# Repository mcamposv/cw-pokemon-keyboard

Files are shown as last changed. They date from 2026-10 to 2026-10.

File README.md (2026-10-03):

# CWPokeKey — Adaptador de teclado USB para CW Pokemon

> [English version](README.en.md)

Firmware para ESP32-S3 que convierte la entrada de un teclado USB estándar al protocolo PS/2, permitiendo usarlo con el jack TRS 3.5mm del [CW Pokemon](https://github.com/admvip/CW-Pokemon-Infomation).

## Objetivo

El [CW Pokemon](https://github.com/admvip/CW-Pokemon-Infomation) es un dispositivo hardware para radioaficionados que decodifica y genera código Morse (CW). Solo acepta teclados PS/2 a través de su jack TRS 3.5mm. Este adaptador soluciona esa limitación usando un ESP32-S3 como host USB HID + transmisor PS/2 por bit-bang.

```
Teclado USB  →  ESP32-S3 (USB OTG Host)  →  PS/2 bit-bang  →  Jack TRS 3.5mm  →  CW Pokemon
```

**Proyecto CW Pokemon (hardware original):** [github.com/admvip/CW-Pokemon-Infomation](https://github.com/admvip/CW-Pokemon-Infomation)

## Lista de materiales

| Cantidad | Componente | Notas |
|---|---|---|
| 1 | ESP32-S3-DevKitC-1 N16R8 | 16 MB flash, 8 MB PSRAM |
| 1 | Jack TRS 3.5mm hembra estéreo (para soldar) | **Imprescindible estéreo** — ver aviso abajo |
| 1 | Cable TRS 3.5mm estéreo (macho-macho) | Para conectar el adaptador al CW Pokemon |
| 1 | Cable USB-C a USB-A OTG (macho-hembra) | Para conectar el teclado al puerto OTG del ESP32 |
| 1 | Cable USB-C | Alimentación del ESP32 (puerto derecho / UART) |
| 1 | Fuente o cargador USB 5V | Para alimentar el ESP32 |
| — | Estaño + soldador | Soldaduras en la placa |
| — | Pistola de hot glue | Sujetar y proteger las soldaduras |

> **Atención:** El jack TRS debe ser **estéreo** (3 contactos: TIP, RING, SLEEVE). Un conector mono (TS, 2 contactos) cortocircuitaría DATA con GND y podría dañar el CW Pokemon.

## Conexión del jack TRS (PS/2)

| Contacto TRS | Señal PS/2 | GPIO ESP32-S3 |
|---|---|---|
| TIP | DATA | GPIO5 |
| RING | CLK | GPIO6 |
| SLEEVE | GND | GND |

**Activar modo teclado en el CW Pokemon:** Menú → tipo de electrónico → **KeyB**

## Modificación hardware — activar USB Host

El DevKitC-1 tiene dos puentes de soldadura (*solder bridges*) en la PCB que hay que cerrar para que el puerto OTG izquierdo funcione como host y suministre alimentación al teclado. De fábrica vienen abiertos. Solo hace falta aplicar una pequeña gota de estaño en cada uno.

### Puente USB-OTG (cara trasera de la placa)

Está en la cara trasera, junto al conector USB-C izquierdo, marcado como **USB-OTG**. Cerrarlo habilita la salida de VBUS (5V) para alimentar el teclado.

| Abierto — estado de fábrica | Cerrado — aplicar estaño |
|:---:|:---:|
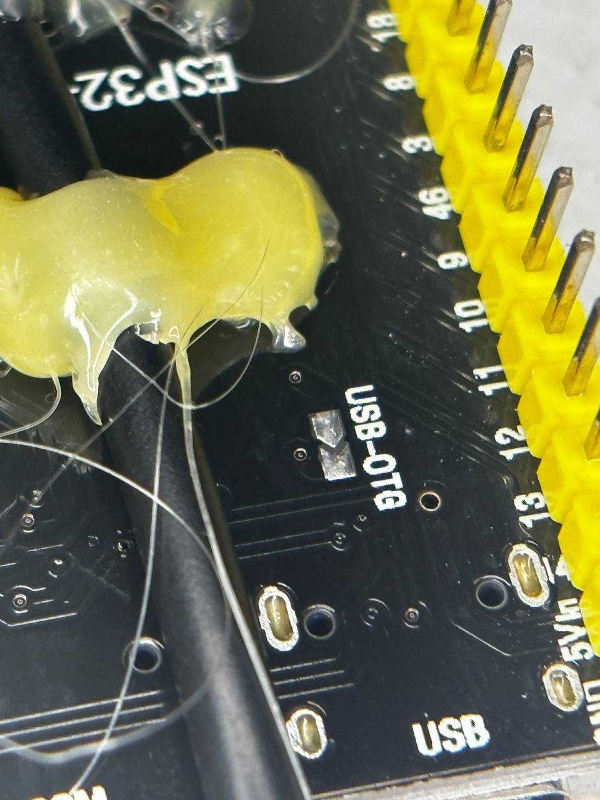
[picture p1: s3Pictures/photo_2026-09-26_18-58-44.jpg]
USB-OTG abierto
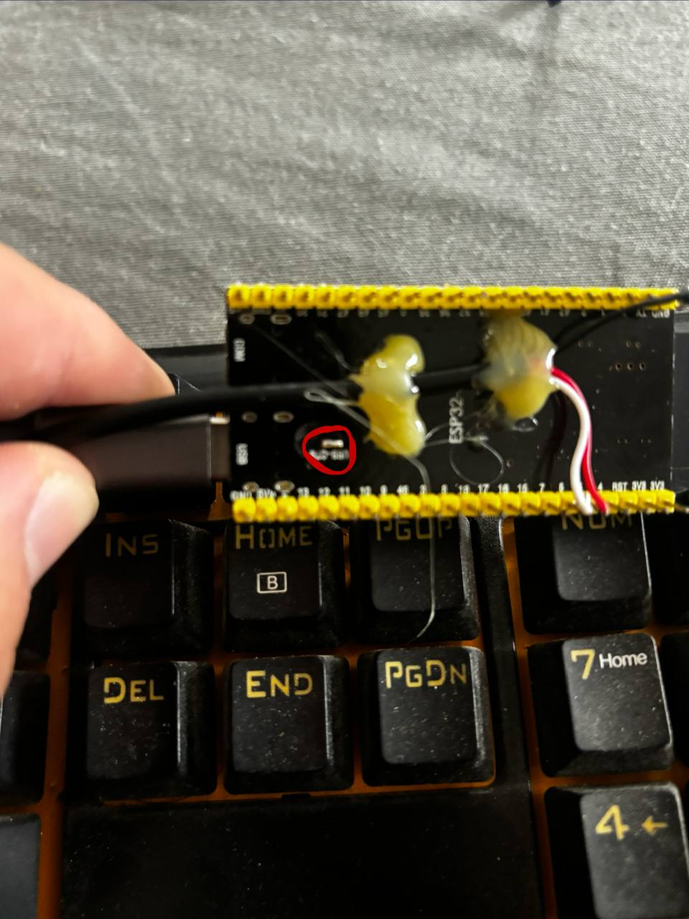
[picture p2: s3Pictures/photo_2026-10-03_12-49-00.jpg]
USB-OTG cerrado
|  |  |

### Puente IN-OUT (cara delantera de la placa)

Está en la cara delantera, también cerca del conector OTG, marcado como **IN-OUT**. Cerrarlo configura la dirección de corriente en modo host (salida). Los dos círculos rojos de la foto señalan ambos puentes ya cerrados.

| Abierto — estado de fábrica | Cerrado — aplicar estaño |
|:---:|:---:|
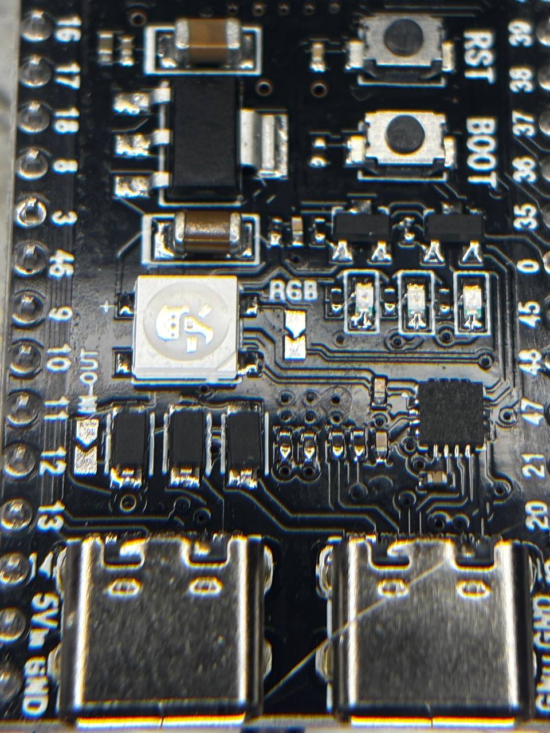
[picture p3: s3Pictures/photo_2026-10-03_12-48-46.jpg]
IN-OUT abierto
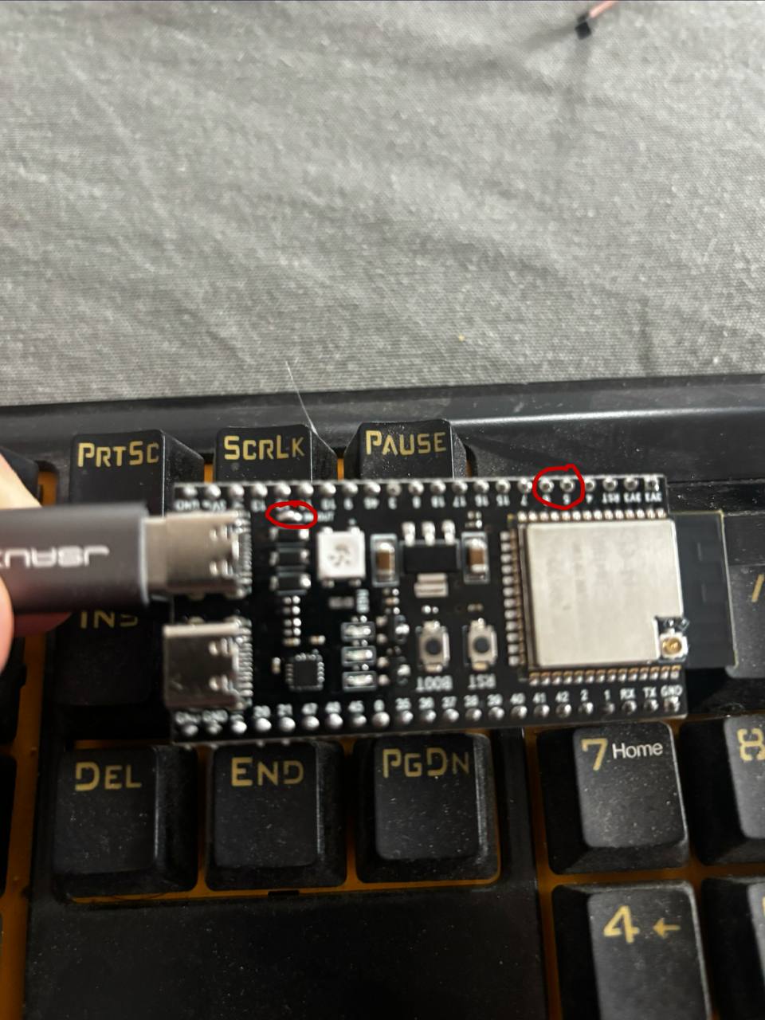
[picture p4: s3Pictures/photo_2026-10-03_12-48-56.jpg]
IN-OUT cerrado
|  |  |

### Vista general tras la modificación

| Cara delantera | Cara trasera |
|:---:|:---:|
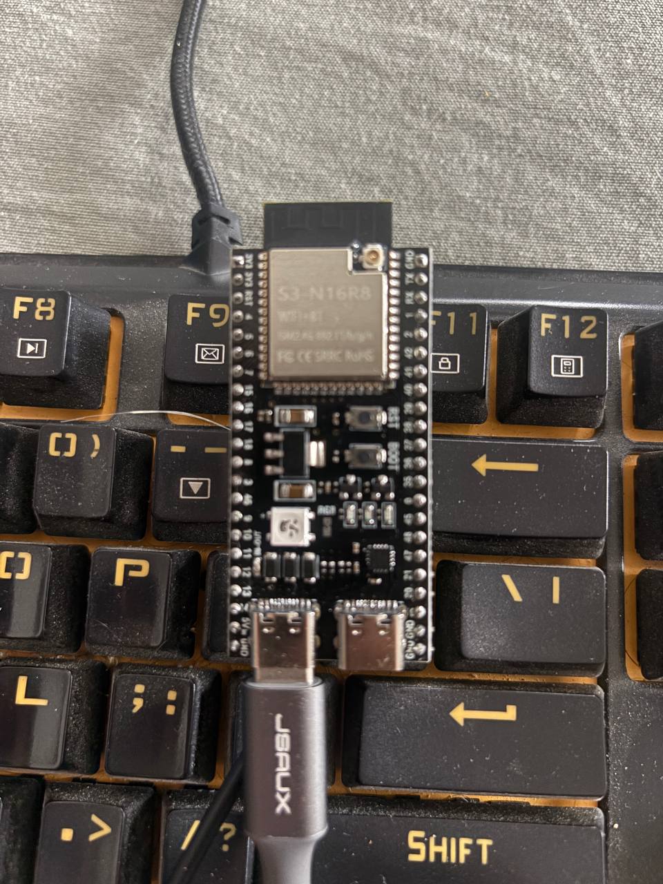
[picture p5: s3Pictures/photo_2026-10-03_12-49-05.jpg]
Vista frontal
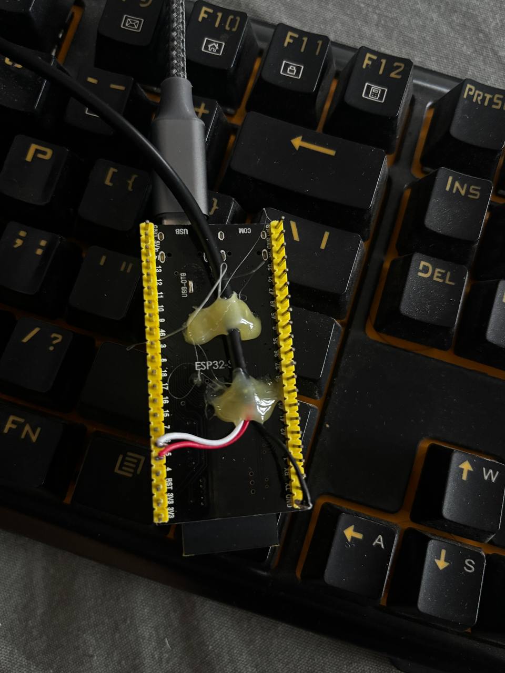
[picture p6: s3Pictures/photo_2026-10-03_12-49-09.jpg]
Vista trasera
|  |  |

## Notas eléctricas importantes

- El CW Pokemon usa lógica **3.3V** — no es necesario convertidor de nivel.
- El pin **CLK (RING)** tiene pull-up interno a **3.2V** en el CW Pokemon.
- El pin **DATA (TIP)** tiene un pull-down interno de **~8 kΩ a GND** en el CW Pokemon.
- **CRÍTICO — modo push-pull en DATA:** Con el pull-up interno de 45 kΩ del ESP32 en modo open-drain, la línea DATA solo alcanza ~0.5 V porque el pull-down de 8 kΩ del CW Pokemon gana. El CW Pokemon lee DATA como LOW constante y todo llega corrupto. Configurando el GPIO en **push-pull** (salida activa), el ESP32 conduce activamente 3.3 V y supera el pull-down. Implementado en `firmware-s3/src/ps2.cpp`.

## Indicador LED (WS2812 RGB, GPIO48)

| Estado | Comportamiento LED |
|---|---|
| Teclado USB conectado | Apagado |
| Esperando teclado | Azul, parpadeo rápido (~120 ms) |

## Compilar y flashear

Requiere [PlatformIO](https://platformio.org/) (extensión VS Code o CLI).

```bash
cd firmware-s3
pio run              # compilar
pio run -t upload    # flashear (puerto /dev/ttyACM0)
pio device monitor   # monitor serie (115200 baud)
```

### Selección de layout de teclado

Editar `firmware-s3/platformio.ini`:

```ini
build_flags =
    -DLAYOUT_ES   ; QWERTY español (por defecto)
;   -DLAYOUT_US   ; QWERTY inglés americano
```

## Caja imprimible en 3D

En la carpeta `box/` hay una caja parametrizada en OpenSCAD para alojar el adaptador. Los STL están listos para slicear directamente.

## Estructura del proyecto

```
firmware-s3/              — Firmware (USB HID Host + PS/2 bit-bang)
├── platformio.ini
└── src/
    ├── config.h          — Asignación de pines y constantes
    ├── ps2.cpp/hpp       — Driver PS/2 bit-bang (modo push-pull)
    ├── usb_kbd.cpp/hpp   — USB HID Host (ESP-IDF usb_host)
    ├── keymap.c/h        — Tabla HID keycode → PS/2 Set 2
    └── main.cpp
box/                      — Caja imprimible en 3D
├── cwpokekey_box.scad    — Fuente OpenSCAD (paramétrica)
├── cwpokekey_body.stl    — Cuerpo (imprimir sin soportes, suelo abajo)
└── cwpokekey_lid.stl     — Tapa  (imprimir sin soportes, cara exterior abajo)
s3Pictures/               — Fotos del hardware y soldaduras
debug/                    — Capturas de pantalla de depuración
```

## Licencia

GNU General Public License v3.0

Copyright (C) 2026 mcamposv

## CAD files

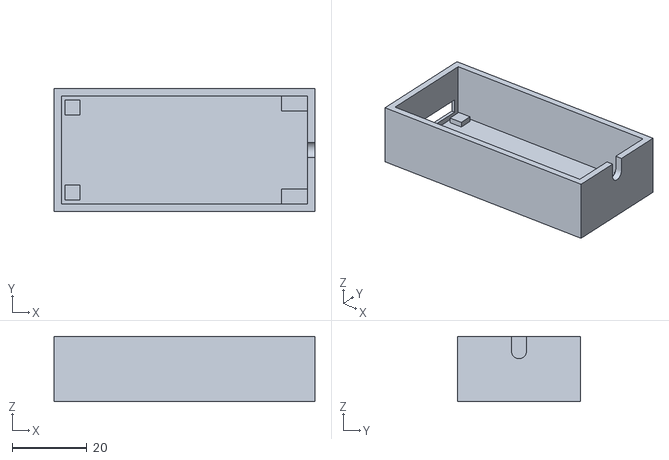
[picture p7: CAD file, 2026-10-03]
box/cwpokekey_body.stl
69.8 x 32.8 x 17.5

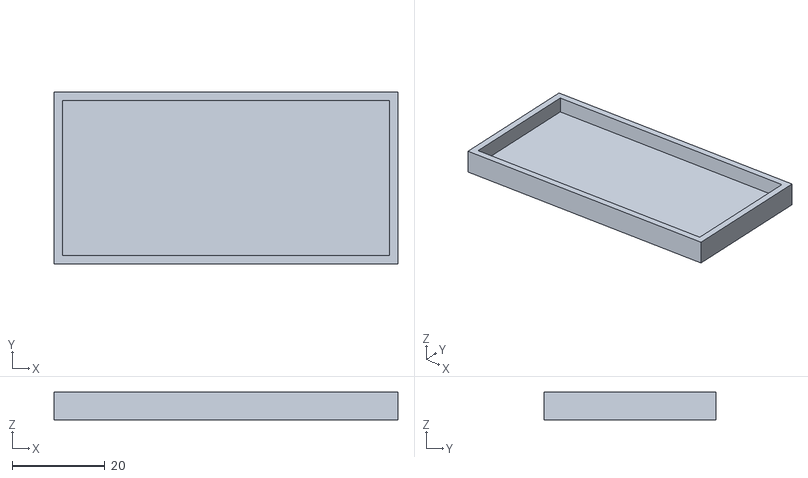
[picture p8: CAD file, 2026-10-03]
box/cwpokekey_lid.stl
74.0 x 37.0 x 6.00

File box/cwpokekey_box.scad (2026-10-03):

// ─────────────────────────────────────────────────────────────────────────────
// CWPokeKey — Caja para ESP32-S3 DevKitC-1
// OpenSCAD paramétrico · tapa a presión (4 clips en los lados largos)
//
// EJES
//   X : eje largo de la placa  (X=0 → pared USB-C  /  X=OL → pared jack TRS)
//   Y : eje ancho (headers)
//   Z : altura
//
// CÓMO USAR
//   F5 = vista previa   F6 = render final   Archivo › Exportar › Export as STL
//
//   Cuerpo : deja  render_box();  y comenta  render_lid();
//   Tapa   : deja  render_lid();  y comenta  render_box();
//
// ORIENTACIÓN DE IMPRESIÓN
//   Cuerpo : suelo hacia abajo — sin soportes
//   Tapa   : cara exterior hacia abajo (girar 180° en el slicer) — sin soportes
//
// AJUSTE
//   TOL     : aumenta si la placa entra muy justa
//   LIP_GAP : aumenta si la tapa no desliza
//   SNAP_D  : reduce si los clips van muy duros
// ─────────────────────────────────────────────────────────────────────────────

$fn = 48;

// ── PLACA ────────────────────────────────────────────────────────────────────

BL = 65;   // largo con headers  (eje X: pared USB-C ↔ pared jack)
BW = 28;   // ancho con headers  (eje Y)
BH = 14;   // alto total (PCB + componentes + pines)

// ── GEOMETRÍA DE CAJA ────────────────────────────────────────────────────────

TOL   = 0.4;  // holgura por lado
WL    = 2.0;  // grosor de pared
FLOOR = 1.5;  // espacio libre bajo la placa

// Dimensiones interiores
IL = BL + 2*TOL;
IW = BW + 2*TOL;
IH = BH + FLOOR;

// Dimensiones exteriores del cuerpo
OL = IL + 2*WL;
OW = IW + 2*WL;
OH = IH + WL;   // WL = suelo sólido

// ── APERTURAS USB-C (pared X=0, extremo corto) ───────────────────────────────
// Dos conectores USB-C centrados en el ancho de la placa

USB_W  = 9.5;   // ancho de cada apertura
USB_H  = 4.0;   // alto de cada apertura
USB_CC = 16.0;  // distancia centro a centro entre los dos conectores
USB_Z  =  2.0;  // altura del centro del conector sobre el fondo de la placa
USB_WL = WL * 0.5;  // grosor de pared en la zona USB (50% de WL)

// ── RANURA JACK TRS (pared X=OL, forma U abierta arriba) ─────────────────────

JACK_R     = 2.0;   // radio ranura → ancho total 4 mm
JACK_DEPTH = 6.0;   // profundidad del canal desde el borde superior (mm)

// ── TAPA — labio de ajuste ────────────────────────────────────────────────────

LIP_D   =  4;   // profundidad del labio de la tapa
LIP_GAP = 0.3;  // holgura labio ↔ exterior de caja

// ── TAPA ─────────────────────────────────────────────────────────────────────

LID_T   = 2.0;  // grosor panel de tapa
LIP_WL  = 1.8;  // grosor del labio de la tapa

// ── CALCULADOS ────────────────────────────────────────────────────────────────

// Centro absoluto (Z) del conector USB desde el exterior del suelo
usb_z_abs = WL + FLOOR + USB_Z;


// ─────────────────────────────────────────────────────────────────────────────
// MÓDULOS
// ─────────────────────────────────────────────────────────────────────────────

// Ranura en U: semicírculo en la base + slot rectangular hasta el borde superior
// Se usa para el hueco del jack en el cuerpo y en la tapa.
// Orientación: la apertura queda en +Z (hacia arriba).
// La geometría se extrude en el eje Y (rotation -90° para cortar pared en X).
// U vertical: apertura en el borde superior (módulo X=0 → mundo Z=OH),
// paredes rectas hasta depth-r, semicírculo en el fondo.
// Ancho total = 2*r  |  Profundidad total = depth
module u_slot_xz(r, thick, depth=0) {
    d = max(r * 2, depth);   // mínimo suficiente para que el semicírculo quepa
    linear_extrude(thick + 0.2)
        union() {
            // Canal recto: desde la apertura hasta el inicio del semicírculo
            translate([0, -r]) square([d - r, r * 2]);
            // Semicírculo en el fondo
            translate([d - r, 0]) circle(r = r);
        }
}

// ─────────────────────────────────────────────────────────────────────────────
// CUERPO
// ─────────────────────────────────────────────────────────────────────────────

module box_body() {
    difference() {
        // Bloque exterior sólido
        cube([OL, OW, OH]);

        // Vaciado interior (abierto por arriba, +1 para limpiar cara superior)
        translate([WL, WL, WL])
            cube([IL, IW, IH + 1]);

        // ── Apertura USB-C (pared X=0) — hueco continuo para ambos puertos ─────
        translate([-0.1, OW/2 - USB_CC/2 - USB_W/2, usb_z_abs - USB_H/2])
            cube([WL + 0.2, USB_CC + USB_W, USB_H]);

        // Rebaje exterior que deja la pared USB con grosor USB_WL (50% de WL)
        translate([-0.1, OW/2 - USB_CC/2 - USB_W/2 - 2, usb_z_abs - USB_H/2 - 2])
            cube([WL - USB_WL + 0.1, USB_CC + USB_W + 4, USB_H + 4]);

        // ── Ranura U jack TRS (pared X=OL) ───────────────────────────────
        // Ranura U: +0.1 sobre OH para evitar cara coplanar en el borde superior
        translate([OL - WL - 0.1, OW/2, OH + 0.1])
            rotate([0, 90, 0])
                u_slot_xz(JACK_R, WL, depth=JACK_DEPTH + 0.1);

    }

    // Topes esquina lado USB (solo soporte de altura, FLOOR mm)
    for (y = [WL + 1, OW - WL - 5])
        translate([WL + 1, y, WL])
            cube([4, 4, FLOOR]);

    // Topes esquina lado jack/antena (7×4×4 mm, encajan la placa lateralmente)
    for (y = [WL, OW - WL - 4])
        translate([OL - WL - 7, y, WL])
            cube([7, 4, 4]);
}

// ─────────────────────────────────────────────────────────────────────────────
// TAPA
// ─────────────────────────────────────────────────────────────────────────────

// El labio envuelve el exterior del cuerpo con holgura LIP_GAP.
// Modelada "al derecho" (cara exterior arriba); para imprimirla,
// girar 180° en el slicer para que la cara exterior quede sobre la cama.

module lid() {
    // Dimensiones exteriores del labio
    ll = OL + 2*(LIP_GAP + LIP_WL);
    lw = OW + 2*(LIP_GAP + LIP_WL);
    // Offset del labio respecto al origen del cuerpo
    lx = -(LIP_GAP + LIP_WL);
    ly = -(LIP_GAP + LIP_WL);

    difference() {
        union() {
            // Panel superior de la tapa
            translate([lx, ly, 0])
                cube([ll, lw, LID_T]);

            // Labio perimetral (baja LIP_D desde el panel)
            translate([lx, ly, LID_T])
                difference() {
                    cube([ll, lw, LIP_D]);
                    // Vaciado interior (deja solo la pared LIP_WL)
                    translate([LIP_WL, LIP_WL, -0.1])
                        cube([ll - 2*LIP_WL, lw - 2*LIP_WL, LIP_D + 0.2]);
                }
        }

    }

}

// Resalte triangular — engancha en la muesca del cuerpo
module snap_bump() {
    linear_extrude(CLIP_W)
        polygon([
            [0, 0],
            [0, LIP_D * 0.6],
            [SNAP_D, LIP_D * 0.4],
            [SNAP_D, 0]
        ]);
}

// ─────────────────────────────────────────────────────────────────────────────
// RENDER
// ─────────────────────────────────────────────────────────────────────────────

module render_box() {
    box_body();
}

module render_lid() {
    // Para preview conjunto: tapa flotando 8 mm sobre el cuerpo
    translate([0, 0, OH + 8])
        lid();
}

// ┌──────────────────────────────────────────────────────┐
// │  DESCOMENTA LO QUE QUIERAS EXPORTAR (uno cada vez)  │
// └──────────────────────────────────────────────────────┘

// ── Posición de impresión: cuerpo y tapa uno al lado del otro ────────────────
// Cuerpo: suelo hacia abajo, apertura arriba — sin soportes
render_box();

// Tapa: panel exterior hacia abajo (Z=0), labio hacia arriba — sin soportes
// Se desplaza OL+10 mm en X para dejar 10 mm de espacio entre piezas
translate([OL + 10 + (LIP_GAP + LIP_WL), 0, 0])
    lid();

// Vista de conjunto montado (tapa flotando sobre el cuerpo):
// render_box(); render_lid();

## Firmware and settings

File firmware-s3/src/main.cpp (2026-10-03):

#include <Arduino.h>
#include "config.h"
#include "version.h"
#include "ps2.hpp"
#include "ble_hid.hpp"
#include "usb_kbd.hpp"

// ── LED helpers ───────────────────────────────────────────────────────────────

static void led(uint8_t r, uint8_t g, uint8_t b) {
    neopixelWrite(PIN_LED_RGB, r, g, b);
}

static void led_task(void* arg) {
    while (true) {
        if (usb_kbd_is_active()) {
            // USB keyboard connected: LED off (physical keyboard = no visual noise)
            led(0, 0, 0);
            vTaskDelay(pdMS_TO_TICKS(500));
        } else if (ble_hid_is_connected()) {
            // BLE connected: slow blue blink
            led(0, 0, 20);
            vTaskDelay(pdMS_TO_TICKS(800));
            led(0, 0, 0);
            vTaskDelay(pdMS_TO_TICKS(800));
        } else {
            // Scanning: fast blue blink
            led(0, 0, 30);
            vTaskDelay(pdMS_TO_TICKS(120));
            led(0, 0, 0);
            vTaskDelay(pdMS_TO_TICKS(120));
        }
    }
}

// ── Setup & loop ──────────────────────────────────────────────────────────────

void setup() {
    led(0, 0, 0);   // kill factory LED immediately
    pinMode(2, OUTPUT);
    digitalWrite(2, LOW);

    Serial.begin(115200);
    delay(500);
    Serial.println("\n=== CWPokeKey v" FIRMWARE_VERSION " ===");
    Serial.println("USB+BLE HID → PS/2 adapter for CW Pokemon");

    ps2_init();
    usb_kbd_init();
    // ble_hid_init();  // BLE disabled for USB-only test

    xTaskCreatePinnedToCore(led_task, "led", 2048, nullptr, 1, nullptr, 1);
}

void loop() {
    // Everything runs in tasks; loop just keeps Arduino runtime happy
    vTaskDelay(pdMS_TO_TICKS(1000));
}

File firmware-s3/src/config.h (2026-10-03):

#pragma once
#include "driver/gpio.h"

// ── PS/2 output pins ──────────────────────────────────────────────────────────
#define PIN_PS2_CLK   GPIO_NUM_6   // TRS RING
#define PIN_PS2_DATA  GPIO_NUM_5   // TRS TIP

// PS/2 timing — 40 μs half-period ≈ 12.5 kHz, well within PS/2 spec (60–100 μs period)
#define PS2_HALF_US   40

// ── Status LED ────────────────────────────────────────────────────────────────
#define PIN_LED_RGB   48           // WS2812 on DevKitC-1

// ── BLE ───────────────────────────────────────────────────────────────────────
#define BLE_RECONNECT_TIMEOUT_S  60   // scan for new device after this many seconds
#define BLE_DEVICE_NAME          "CWPokeKey"

// ── NVS namespace ────────────────────────────────────────────────────────────
#define NVS_NAMESPACE  "cwkey"
#define NVS_KEY_ADDR   "ble_addr"

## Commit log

2026-10-03 feat: initial commit — ESP32-S3 CWPokeKey USB+BLE keyboard adapter
    Firmware ESP32-S3 que convierte teclados USB y BLE a PS/2 para el CW Pokemon.
    Incluye scanner WiFi+BLE de diagnóstico y fotos del hardware.
2026-10-03 feat: only-usb — USB keyboard to PS/2 adapter, no BLE
    Firmware mínimo USB→PS/2 para ESP32-S3. Sin BLE, sin escáner de diagnóstico.
    Solo firmware-s3 con USB HID host + PS/2 bit-bang + fotos + documentación.
2026-10-03 docs: actualizar link CW Pokemon y ampliar lista de materiales
    - Link del proyecto CW Pokemon → github.com/admvip/CW-Pokemon-Infomation
    - BOM ampliado: cables finos, fuente USB, hot glue, cable TRS
    - Explicación de por qué un adaptador USB-C OTG estándar no es suficiente
    (el puerto OTG del DevKitC-1 no suministra VBUS sin mod hardware)
2026-10-03 docs: simplificar mod USB — cable OTG + 2 pads de alimentación
    Sustituye conector USB-A soldado por cable USB-C a USB-A OTG estándar.
    La modificación queda en soldar solo 2 cables (5V y GND) en los pads
    del conector OTG para alimentar el teclado. Referencia foto con círculos rojos.
2026-10-03 refactor: eliminar referencias BLE — proyecto USB únicamente
    - main.cpp: quita include ble_hid, bloque BLE en led_task y ble_hid_init
    - platformio.ini: elimina NimBLE como dependencia y flag NIMBLE
    - README.md / README.en.md: elimina secciones 'Ramas' y 'Timing PS/2',
    quita fila BLE del LED, actualiza estructura del proyecto
2026-10-03 Revert "refactor: eliminar referencias BLE — proyecto USB únicamente"
    This reverts commit 463c44deb4e6934accee553fb6ecc8c13c4e801c.
    [main.cpp]
2026-10-03 docs: reescribir mod hardware — cerrar puentes USB-OTG e IN-OUT
    Sustituye la explicación incorrecta de soldadura de cables por la
    correcta: cerrar los dos solder bridges de la PCB. Fotos embebidas
    en el documento con comparativas antes/después para cada puente.
    Elimina entrada de cables finos del BOM.
2026-10-03 Add CI/CD release workflow, versioning system and 3D enclosure
    - GitHub Actions workflow (.github/workflows/release.yml): builds firmware
    with PlatformIO and publishes a GitHub Release with the .bin artifact
    on every vX.Y.Z tag push
    - firmware-s3/src/version.h: default "dev" for local builds; CI stamps
    the tag version before compiling so Serial output shows the real version
    - firmware-s3/src/main.cpp: uses FIRMWARE_VERSION macro from version.h
    - box/cwpokekey_box.scad: parametric OpenSCAD enclosure for the ESP32-S3
    DevKitC-1 (65×28×14 mm board); snap-fit lid, USB-C cutouts on one short
    end, U-slot for TRS jack on the opposite end
    - box/cwpokekey_body.stl + cwpokekey_lid.stl: pre-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
    [cwpokekey_body.stl, cwpokekey_box.scad, cwpokekey_lid.stl]
2026-10-03 Finalize 3D enclosure and add box reference to docs
    - Update cwpokekey_box.scad: continuous USB opening (no center pillar),
    1mm thinned USB wall, corner alignment posts on jack/antenna side (7×4×4mm),
    4×6mm U-slot for TRS cable (clean top edge, no render artefact), snap
    bumps removed (friction-fit lid)
    - Regenerate cwpokekey_body.stl and cwpokekey_lid.stl
    - Add brief 3D enclosure section to README.md and README.en.md
    [cwpokekey_body.stl, cwpokekey_box.scad, cwpokekey_lid.stl]
